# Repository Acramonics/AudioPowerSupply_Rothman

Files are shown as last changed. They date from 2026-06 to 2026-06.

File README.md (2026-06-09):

AudioPowerSupply
================

Board Design: Andrew Martin, Acramonics, 2026

Circuit Design: Jake Rothmann

Overview
--------

This is a redesign of the PCB for Jake Rothmann's dual-rail power
supply for high quality audio work. The original board is rather large
and this version has been shrunk for use in my builds.

Note that the board suppors 15V-0-15V, 21V-0-21V, or 48V single rail.

The 21V-0-21V is designed as the best supply for NE5532s, but the
newer versions of these only support up to 18V-0-18V rails.

The 48V single rail is designed for microphone phantom power.

The component values in the schematic are for the 21V-0-21V version
(except where components are not present in that version, where they
are for the 15V-0-15V version). **Make sure to read the schematic
together with the BOM**

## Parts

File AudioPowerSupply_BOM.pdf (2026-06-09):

AudioPowerSupply

Reference | Qty | Value | Footprint
| 15V-0-15V | 21V-0-21V | 48V Single
C1,C2 | 2 1000uF 63V | 1000uF 63V | 220uF 100V | D16.0mm_P7.50mm
C3,C4 | 2 10uF 50V | 10uF 50V | 10uF 50V | D5.0mm_P2.50mm
C5 | 2 470nF | 470nF | 10uF 63V | L7.2mm_W3.0mm_P5.00mm
C6 | 2 470nF | 470nF | omit | L7.2mm_W3.0mm_P5.00mm
C7,C8 | 2 470uF >30V | 220uF >42V | omit | D10.0mm_P5.00mm
C9 | 1 10nF | 10nF | 10nF | L7.2mm_W3.0mm_P5.00mm
C10,C11,C12 | 3 100nF | 100nF | 100nF | L7.2mm_W3.0mm_P5.00mm
D1,D2,D3,D4 | 4 1N4002 / SB40 | 1N4004 | 1N4004 | DO-41
D5,D6 | 2 1N4002 | ZY24(24V/2W Zener) ZY24(24V/2W Zener) DO-41
D7 | 1 1N4002 | 1N4002 | 1N4002 | DO-41
D8 | 1 1N4148 | 1N4148 | 1N4148 | DO-35
J1,J4,J5,J6,J7 | 5 Conn_01x03_Pin | Conn_01x03_Pin | Conn_01x03_Pin | TerminalBlock 1x03 P3.50mm
J2 | 1 Conn_01x02_Pin | Conn_01x02_Pin | Conn_01x02_Pin | Molex KK-254 1x02 P2.54mm
J3 | 1 Conn_01x03_Pin | Conn_01x03_Pin | Conn_01x03_Pin | Molex KK-254 1x03 P2.54mm
L1 | 1 (10uH) | (10uH) | omit | L9.5mm_D4.0mm_P12.70mm
LED1 | 1 LED | LED | LED | (Off board)
PTC1 | 1 (XF050 500mA) | XF050 500mA | XF050 170mA | D9mm_W3.3mm_P5mm
Q1 | 1 (BC337) | omit | omit | TO-92
Q2 | 1 BC327 | BC327 | BC327 | TO-92
R1 | 1 2R2 2.5W | 2R2 2.5W | 2R2 2.5W | L11.9mm_D4.5mm_P15.24mm
R2 | 1 3K3 1W | 5K6 1W | 9K1 1W | L11.9mm_D4.5mm_P15.24mm
R3 | 1 (6R2) | omit | omit | L6.3mm_D2.5mm_P10.16mm
R4 | 1 (12R) | omit | omit | L6.3mm_D2.5mm_P10.16mm
R5 | 1 2K7 | 8K2 | 9K1 | L6.3mm_D2.5mm_P10.16mm
R6 | 1 omit | 3K3 | 6K2 | L6.3mm_D2.5mm_P10.16mm
R7 | 1 120R | 120R | 120R | L6.3mm_D2.5mm_P10.16mm
R8 | 1 56K | 56K | 56K | L6.3mm_D2.5mm_P10.16mm
R9,R10 | 2 100K | 100K | omit | L6.3mm_D2.5mm_P10.16mm
R11,R12 | 2 47R | 47R | omit | L6.3mm_D2.5mm_P10.16mm
R13 | 1 (22R) | (22R) | omit | L6.3mm_D2.5mm_P10.16mm
R14 | 1 1K | 1K | 1K | L6.3mm_D2.5mm_P10.16mm
R15 | 1 Linked out | 2R2 2.5W | 10R 2.5W | L11.9mm_D4.5mm_P15.24mm
R16 | 1 Linked out | 10R | 10R | L6.3mm_D2.5mm_P10.16mm
RV1 | 1 omit | 10K | 5K | Piher_PT-10-V05_Vertical
RV2 | 1 100K | 100K | omit | Piher_PT-10-V05_Vertical
U1 | 1 LM317_TO-220 | LM317_TO-220 | LM317_TO-220 | TO-220
U2 | 1 NE5532/LM1458 | NE5532 | omit | DIP-8
Transformer | 1 28V / 140mA (5VA) 18-0-18(26V) / 15VA | 24-0-24(48V) / 15VA | (Off board)
| or 25V / 15VA
Heatsink | >18K/W+ | >21K/W | >21K/W | TO-220 twisted vane

Either user PTC1 or Q1/R3/R4
L1/R13 normally linked out
Note that newer NE5532s (like LM1458) only support 18V-0-18V

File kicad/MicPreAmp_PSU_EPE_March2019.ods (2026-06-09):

 | Microphone preamp PSU (15v-0-15v) EPE March 2019
 |  |  | Quantity | Stocked | RS |  | Ebay |  | Total
 | Resistors |  |  |  | Code | Price | Price
R1,R15 | 2R2 | 2.5W | 2 | N | 214-2409 | 0.38 |  |  | 0.76
R2 | 3K3...5K6 (for LED) | 1W | 1 | Y |  | 0 |  |  | 0
R3 | 6R2 |  | 1 | N | 187-0839 | 0.04 |  |  | 0.04
R4 | 12R |  | 1 | Y |  | 0 |  |  | 0
R6 | 2K7/8K2 | 0.5W | 1 | Y |  | 0 |  |  | 0
R7 | 120R |  | 1 | Y |  | 0 |  |  | 0
R8 | 56K |  | 1 | Y |  | 0 |  |  | 0
R9,R10 | 100K |  | 2 | Y |  | 0 |  |  | 0
R11 | 47R |  | 2 | Y |  | 0 |  |  | 0
R13 | 22R |  | 1 | Y |  | 0 |  |  | 0
R14 | 1K |  | 1 | Y |  | 0 |  |  | 0
 |  |  |  |  |  |  |  |  | 0
 | Ceramic caps |  |  |  |  |  |  |  | 0
 | 470nF |  | 2 | N | 194-0546 | 0.17 |  |  | 0.34
 | 10nF |  | 2 | Y |  | 0 |  |  | 0
 | 100nF |  | 2 | Y |  | 0 |  |  | 0
 |  |  |  |  |  |  |  |  | 0
 | Elect (radial) |  |  |  |  |  |  |  | 0
 | 1000-2200uF | 50V | 2 | N | 711-1510 | 1.52 |  |  | 3.04
 | 10-100uF | 50V | 1 | N | 737-4210 | 0.15 |  |  | 0.15
 | 10uF | 50V | 1 | Y |  | 0 |  |  | 0
 | 470uF | 25V | 2 | Y |  | 0 |  |  | 0
 |  |  |  |  |  |  |  |  | 0
 | Semiconductors |  |  |  |  |  |  |  | 0
 | LM317T |  | 1 | N | 714-0792 | 0.54 |  |  | 0.54
 | LM1458 |  | 1 | N | 461-060 | 0.99 |  |  | 0.99
 | 1N4002 |  | 5 | Y |  | 0 |  |  | 0
 | 1N4001 |  | 2 | Y |  | 0 |  |  | 0
 | 1N4148 |  | 1 | Y |  | 0 |  |  | 0
 | BC337 |  | 1 | Y |  | 0 |  |  | 0
 | BC327 |  | 1 | Y |  | 0 |  |  | 0
 |  |  |  |  |  |  |  |  | 0
 | Misc |  |  |  |  |  |  |  | 0
 | Polyswitch 0.5A XF050 |  | 1 | N |  |  | 0.06 |  | 0
 | TO220 21C/W Heatsink |  | 1 | N | 712-4295 | 1.08 |  |  | 1.08
 | 3-term screw connector |  | 1 | Y |  | 0 |  |  | 0
 | 3-way Molex header |  | 2 | N | 483-8477 | 0.28 |  |  | 0.56
 | 3-way Molex housing |  | 2 | N | 679-5375 | 0.11 |  |  | 0.22
 | Molex crimp contact |  | 8 | N | 467-598 | 0.08 |  |  | 0.64
 | 2-way Molex header |  | 1 | N | 483-8461 | 0.24 |  |  | 0.24
 | 2-way Molex housing |  | 1 | N | 679-5363 | 0.11 |  |  | 0.11
 | Case (>150x110x50) | 171x121x55 | 1 | N | 181-1229 | 12.26 |  |  | 0
 |  |  |  |  |  |  |  |  | 0
 | Transformer |  |  |  |  |  |  |  | 0
 | JIM Electronics 28V 140mA |  | 1 | N |  |  |  |  | 0
 | -or- |  |  |  |  |  |  |  | 0
 | 15-0-15 | 6VA | 1 | N | 504-773 | 6.33 |  |  | 6.33
 |  |  |  |  |  |  |  | TOTAL | 15.04
 | 182x120x55
 | Rapid online | Hammond 26827PSLA Eddystone Die Cast Enclosure 188 x 120 x 57mm |  |  |  |  |  | 11.72 | 14.064
 |  | CamdenBoss 5100-247 Project Diecast Natural 187 x 119 x 56mm 5100 Series |  |  |  |  |  | 11.73 | 14.076
 |  | Hammond 1590D Diecast Enclosure Natural (187.5 x 119.5 x 56mm) |  |  |  |  |  | 13.33 | 15.996
 | >150x110x50 | Hammond 1444-12 Aluminium Chassis 178x127x51mm Natural |  |  |  |  |  | 10.77 | 12.924
 |  | Hammond 1550E IP54 Diecast Aluminium Enclosure Natural (171 x 121 x 55mm) |  |  |  |  |  | 11.04 | 13.248

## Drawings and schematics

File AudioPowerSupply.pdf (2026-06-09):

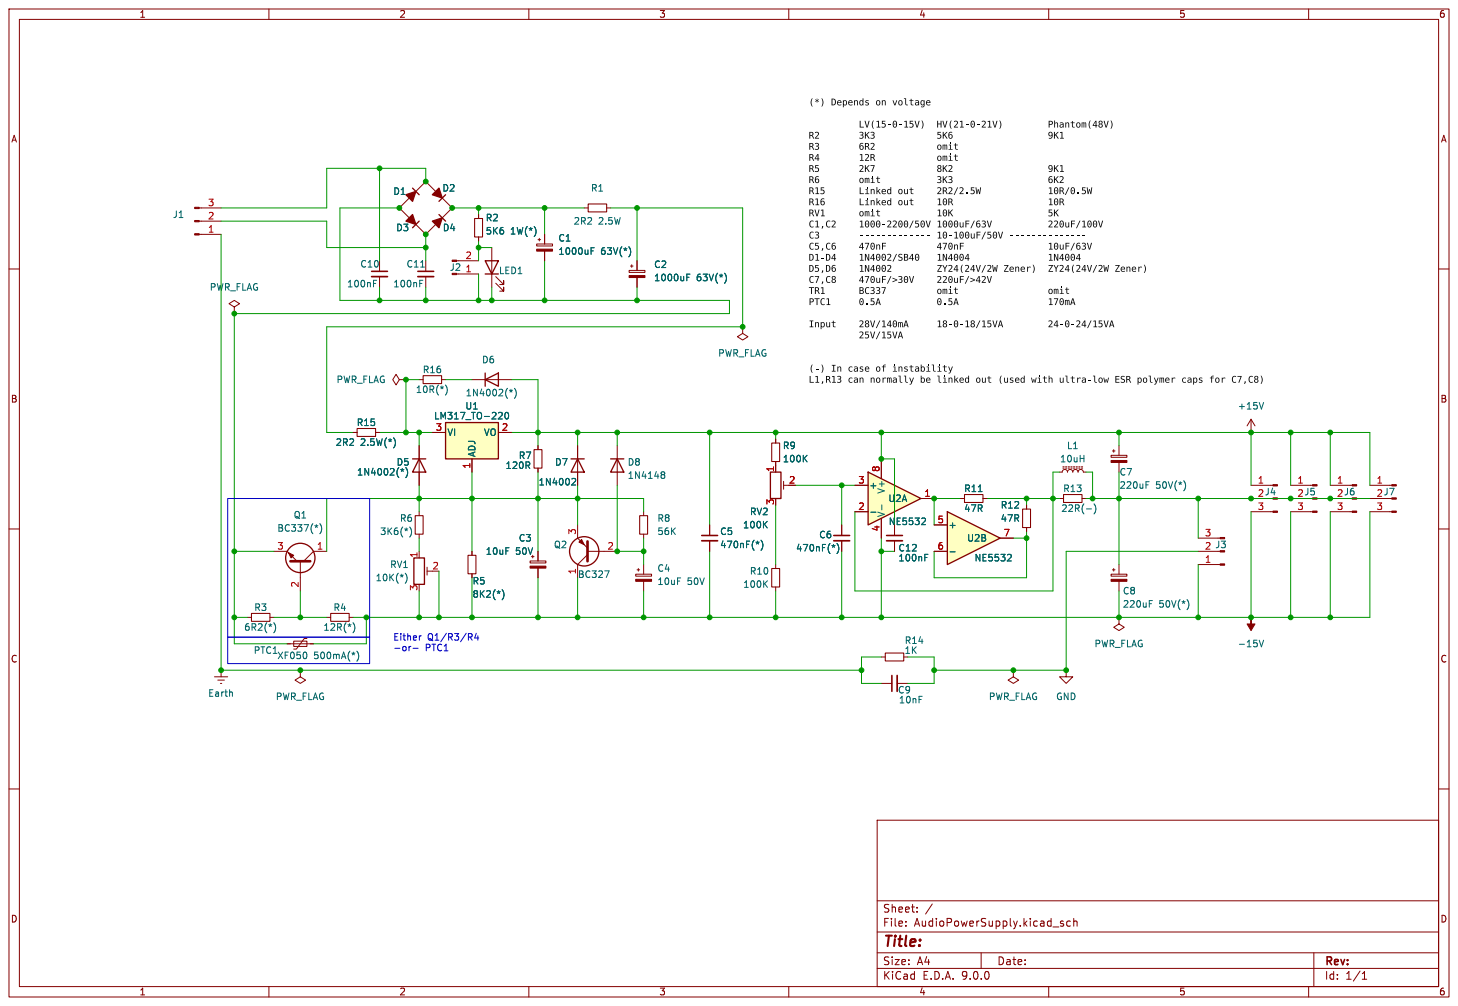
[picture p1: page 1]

Id: 1/1 Title: File: AudioPowerSupply.kicad_sch Sheet: /

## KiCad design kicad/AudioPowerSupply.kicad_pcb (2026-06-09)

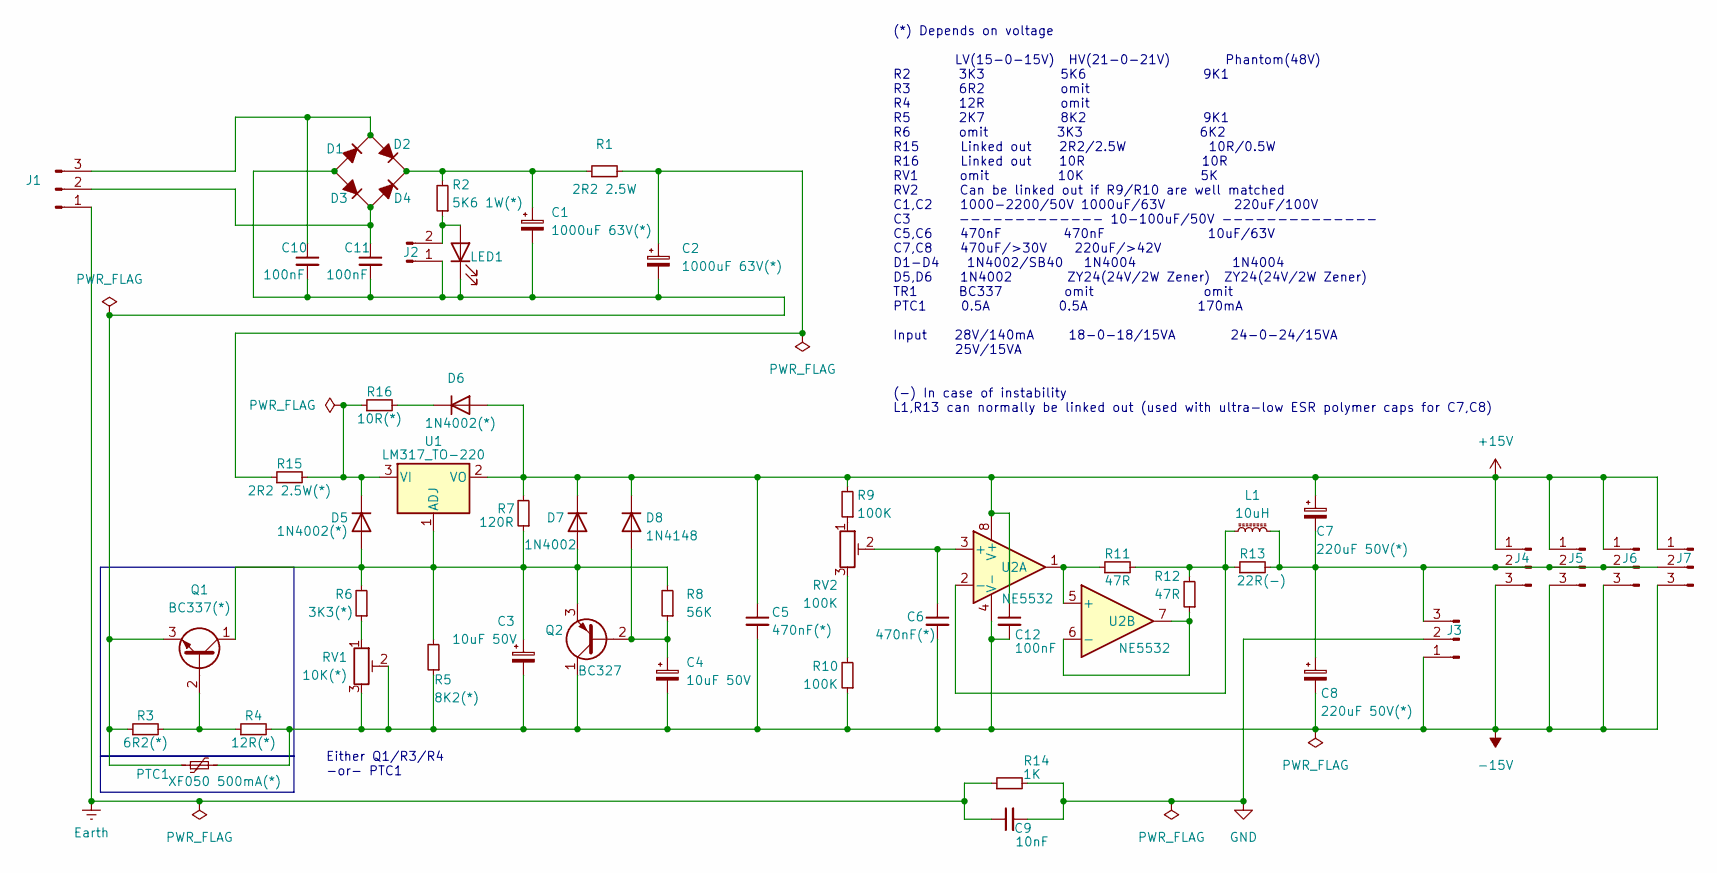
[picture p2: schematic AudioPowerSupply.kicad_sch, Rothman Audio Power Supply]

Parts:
C1, C2: 1000uF 63V(*); CP_Radial_D16.0mm_P7.50mm
C3, C4: 10uF 50V; CP_Radial_D5.0mm_P2.50mm
C5, C6: 470nF(*); C_Rect_L7.2mm_W3.0mm_P5.00mm_FKS2_FKP2_MKS2_MKP2
C7, C8: 220uF 50V(*); CP_Radial_D10.0mm_P5.00mm
C9: 10nF; C_Rect_L7.2mm_W3.0mm_P5.00mm_FKS2_FKP2_MKS2_MKP2
C10, C11, C12: 100nF; C_Rect_L7.2mm_W3.0mm_P5.00mm_FKS2_FKP2_MKS2_MKP2
D1, D2, D3, D4: 1N4001; D_DO-41_SOD81_P10.16mm_Horizontal
D5, D6: 1N4002(*); D_DO-41_SOD81_P10.16mm_Horizontal
D7: 1N4002; D_DO-41_SOD81_P10.16mm_Horizontal
D8: 1N4148; D_DO-35_SOD27_P7.62mm_Horizontal
J1, J4, J5, J6, J7: Conn_01x03_Pin; TerminalBlock_4Ucon_1x03_P3.50mm_Vertical
J2: Conn_01x02_Pin; Molex_KK-254_AE-6410-02A_1x02_P2.54mm_Vertical
J3: Conn_01x03_Pin; PinHeader_1x03_P2.54mm_Vertical
L1: 10uH; L_Axial_L9.5mm_D4.0mm_P12.70mm_Horizontal_Fastron_SMCC
LED1: LED
PTC1: XF050 500mA(*); RV_Disc_D9mm_W3.3mm_P5mm
Q1: BC337(*); TO-92_Inline
Q2: BC327; TO-92_Inline
R1: 2R2 2.5W; R_Axial_DIN0414_L11.9mm_D4.5mm_P15.24mm_Horizontal
R2: 5K6 1W(*); R_Axial_DIN0414_L11.9mm_D4.5mm_P15.24mm_Horizontal
R3: 6R2(*); R_Axial_DIN0207_L6.3mm_D2.5mm_P10.16mm_Horizontal
R4: 12R(*); R_Axial_DIN0207_L6.3mm_D2.5mm_P10.16mm_Horizontal
R5: 8K2(*); R_Axial_DIN0207_L6.3mm_D2.5mm_P10.16mm_Horizontal
R6: 3K3(*); R_Axial_DIN0207_L6.3mm_D2.5mm_P10.16mm_Horizontal
R7: 120R; R_Axial_DIN0207_L6.3mm_D2.5mm_P10.16mm_Horizontal
R8: 56K; R_Axial_DIN0207_L6.3mm_D2.5mm_P10.16mm_Horizontal
R9, R10: 100K; R_Axial_DIN0207_L6.3mm_D2.5mm_P10.16mm_Horizontal
R11, R12: 47R; R_Axial_DIN0207_L6.3mm_D2.5mm_P10.16mm_Horizontal
R13: 22R(-); R_Axial_DIN0207_L6.3mm_D2.5mm_P10.16mm_Horizontal
R14: 1K; R_Axial_DIN0207_L6.3mm_D2.5mm_P2.54mm_Vertical
R15: 2R2 2.5W(*); R_Axial_DIN0414_L11.9mm_D4.5mm_P15.24mm_Horizontal
R16: 10R(*); R_Axial_DIN0207_L6.3mm_D2.5mm_P10.16mm_Horizontal
RV1: 10K(*); Potentiometer_Piher_PT-10-V05_Vertical
RV2: 100K; Potentiometer_Piher_PT-10-V05_Vertical
U1: LM317_TO-220; TO-220-3_Vertical
U2: NE5532; DIP-8_W7.62mm

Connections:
+15V: C5.1, C7.1, C12.1, D6.2 (A), D7.1 (K), D8.1 (K), J4.1, J5.1, J6.1, J7.1, R7.2, R9.2, U1.2 (VO), U2.8 (V+)
-15V: C3.2, C4.2, C5.2, C6.2, C8.2, C12.2, J3.1, J4.3, J5.3, J6.3, J7.3, PTC1.2, Q2.1 (C), R4.2, R5.1, R10.1, RV1.2, RV1.3, U2.4 (V-)
Earth: C9.1, J1.1, R14.1
GND: C9.2, J3.2, R14.2
unnamed: C2.1, R1.2, R15.1
unnamed: C1.2, C2.2, C10.2, C11.2, D1.2 (A), D3.2 (A), J2.1, LED1.1 (K), PTC1.1, Q1.3 (E), R3.1
unnamed: C10.1, D1.1 (K), D2.2 (A), J1.3
unnamed: C1.1, D2.1 (K), D4.1 (K), R1.1, R2.2
unnamed: C11.1, D3.1 (K), D4.2 (A), J1.2
unnamed: C3.1, D5.2 (A), D7.2 (A), Q1.1 (C), Q2.3 (E), R5.2, R6.2, R7.1, R8.2, U1.1 (ADJ)
unnamed: D5.1 (K), R15.2, R16.1, U1.3 (VI)
unnamed: D6.1 (K), R16.2
unnamed: C4.1, D8.2 (A), Q2.2 (B), R8.1
unnamed: J2.2, LED1.2 (A), R2.1
unnamed: C7.2, C8.1, J3.3, J4.2, J5.2, J6.2, J7.2, L1.2, R13.2
unnamed: Q1.2 (B), R3.2, R4.1
unnamed: R6.1, RV1.1
unnamed: R9.1, RV2.1
unnamed: R10.2, RV2.3
unnamed: C6.1, RV2.2, U2.3 (+)
unnamed: L1.1, R11.2, R12.2, R13.1, U2.2 (-)
unnamed: R11.1, U2.1, U2.5 (+)
unnamed: R12.1, U2.6 (-), U2.7

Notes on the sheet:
Either Q1/R3/R4 -or- PTC1
(*) Depends on voltage LV(15-0-15V) HV(21-0-21V) Phantom(48V) R2 3K3 5K6 9K1 R3 6R2 omit R4 12R omit R5 2K7 8K2 9K1 R6 omit 3K3 6K2 R15 Linked out 2R2/2.5W 10R/0.5W R16 Linked out 10R 10R RV1 omit 10K 5K RV2 Can be linked out if R9/R10 are well matched C1,C2 1000-2200/50V 1000uF/63V 220uF/100V C3 -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

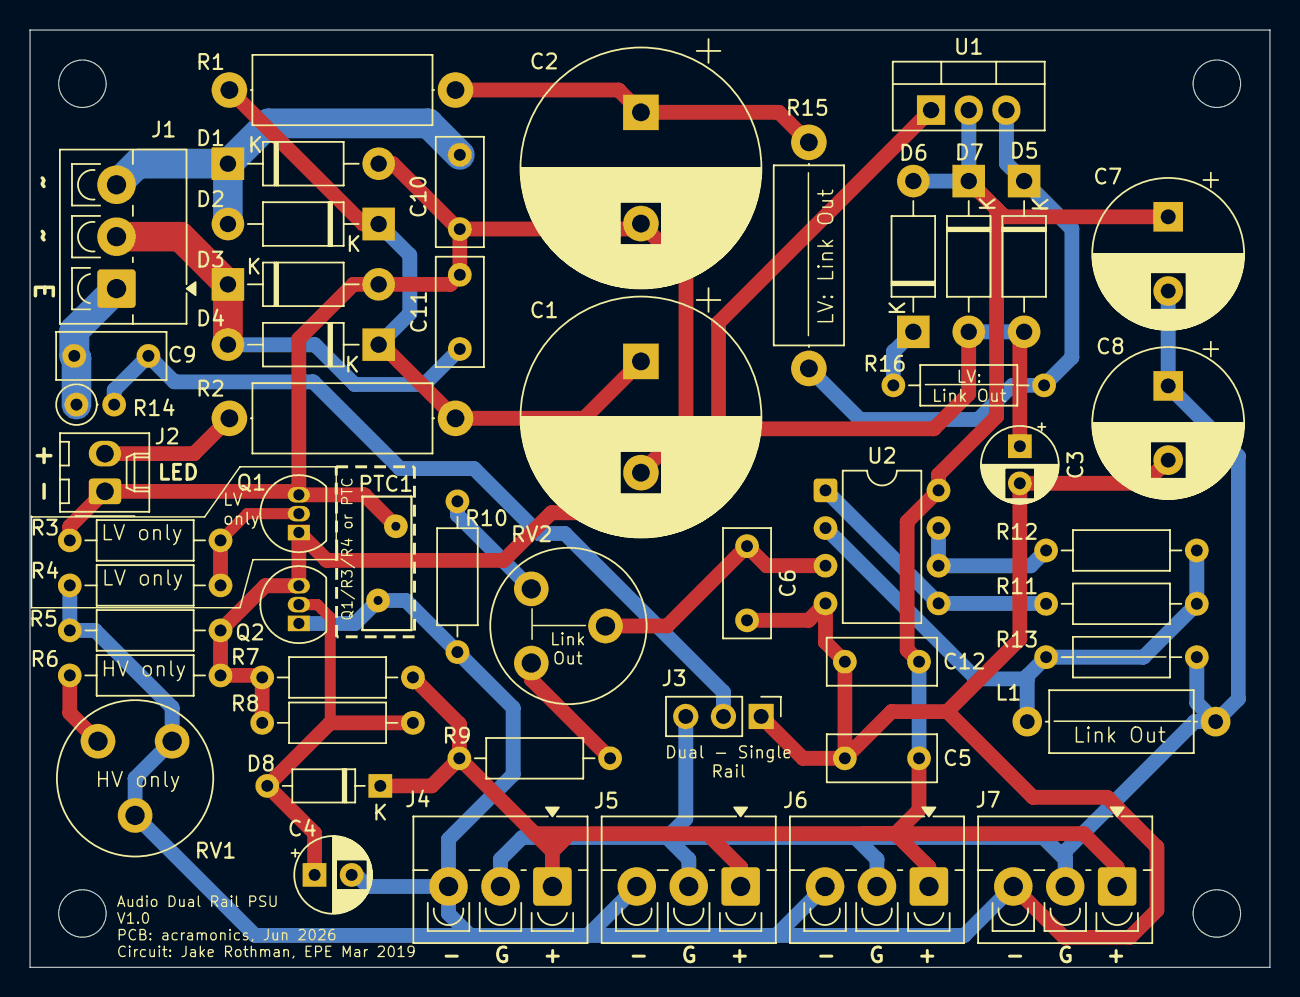
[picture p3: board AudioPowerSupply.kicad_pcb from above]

Board: 2 copper layers, 83.6 x 63.2 mm, 51 parts (0 on the bottom side), 23 nets.

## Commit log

2026-06-09 Complete V1.0
    [AudioPowerSupply.kicad_pcb, AudioPowerSupply.kicad_sch, AudioPowerSupply_BOM.ods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]
2026-06-09 Renamed gerber zip
